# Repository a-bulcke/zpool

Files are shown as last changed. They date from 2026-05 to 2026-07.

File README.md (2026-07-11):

# zpool V2
Carte Zigbbe de gestion de piscine avec mesure pH, Orp, température et pression

### ATTENTION ERREUR R26=0 ohm

zPool

**Les nouveautés :** 

    Filtre sur l'alimentation USB du Xiao

    Régulation LDO coté capteurs pour enlever les bruits provenant du Xiao et de l'ADM3260.

    Alimentation AOP et ADS1115 en 4.7V

    Utilisation d'une référence de tension 2.35V (4.7/2) au lieu des ponts diviseurs non bufferisés

    Gain Orp passe de 2.32 à 2

    Guard ring pour éviter les courants de fuite au niveau des sondes (dont l'impédance est très élevé ce qui peut expliquer l'éventuelle dérive sur la v1.0)

    Connecteur I2C en 3.3V pour écran Oled ou autre

**Sources :** 

https://github.com/Loic74650/pH_Orp_Board

https://www.360customs.de/fr/2019/12/orp-redox-ph-elektrometer-shield-fuer-wemos-d1-mini-mit-lmp7721-ads1115-adm3260/

https://www.ti.com/lit/ds/symlink/lmp7721.pdf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

## Xiao ESP32C6
Utilisation d'un ESP32C6 pour en faire un routeur Zigbee.

Fonctionne avec Zigbee2Mqtt sous Home Assistant.

La carte mesure le pH, l’ Orp, la température et la pression.

La gestion des pompes est assurée par des prises Zigbee c’est plus simple que d’ajouter des relais à la carte.

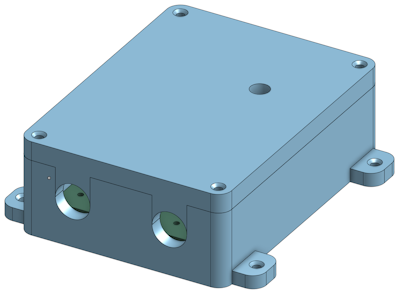
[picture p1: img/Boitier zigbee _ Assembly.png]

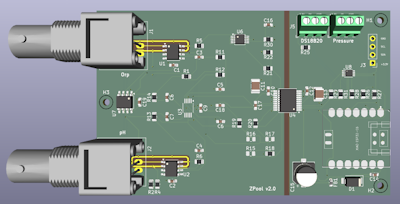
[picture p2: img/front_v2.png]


Capteur de température DS18B20


Capteur de pression 30 Psi


# Branchements #
## température et pression ##



## pH et Orp ##

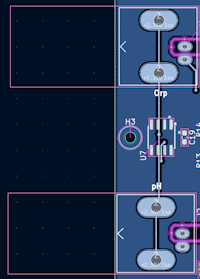
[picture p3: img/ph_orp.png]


# Zigbee2Mqtt #
Dans Zigbee2mqtt sous Home Assistant, laller dans le menu `Paramètres` puis `console de developpement - convertisseurs externes` :



Créer un nouveau convertisseur (de nom ZPool.js) et coller le contenu de [ZPool.js](https://github.com/a-bulcke/zpool/blob/main/zigbee2mqtt/ZPool.js)

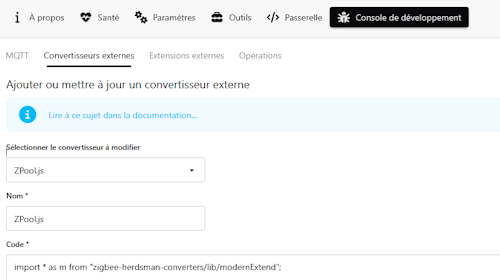
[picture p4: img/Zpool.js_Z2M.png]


Redémarrer Zigbee2mqtt puis autoriser l'association.

# Mise à jour

## Programmation - Mise à jour

Dans Arduino IDE

Dans File - Preferences... ajouter :

```https://espressif.github.io/arduino-esp32/package_esp32_index.json```

Choisir une carte XIAO_ESP32C6 :

<img width="678" height="305" alt="image" src="https://github.com/user-attachments/assets/d0d6836c-16a6-46c1-87e2-4705d107b142" />

<img width="360" height="305" alt="image" src="https://github.com/user-attachments/assets/5ee56a3f-e4a6-4aa4-a9af-70fcf8b1b8bd" />

Dans Tools choisir Partition scheme: "Zigbee ZCZR 4MB with spiffs" et Zigbee Mode: "ZCZR (coordinator/router)"

<img width="718" height="263" alt="image" src="https://github.com/user-attachments/assets/d69159c5-b0cd-445a-aaad-a5ce7c5304e6" />

Et copier coller le code dans Arduino IDE :

Mettre ```Erase All Flash before sketch Upload : Disabled``` pour conserver l'appairage zigbee

<img width="504" height="548" alt="image" src="https://github.com/user-attachments/assets/88b685ce-3d30-4234-acdd-36c6a44c3e30" />

Installer les bibliothèques : 
Chercher et installer : 
```
#include "OneWireESP32.h" //esp32-ds18b20 par junkfix
#include <ADS1X15.h> //ADS1X15 par Rob Tillaart
#include "RunningAverage.h" // RunningAverage par Rob Tillaart
```
<img width="340" height="249" alt="image" src="https://github.com/user-attachments/assets/61d23882-cdc2-45de-8c77-091b2764080c" />

<img width="333" height="298" alt="image" src="https://github.com/user-attachments/assets/ee26f123-cd82-4b68-ad05-28b897d303d5" />

Puis Upload :

<img width="432" height="128" alt="image" src="https://github.com/user-attachments/assets/c4538ff6-32a3-41d7-afa3-70f6845f523d" />

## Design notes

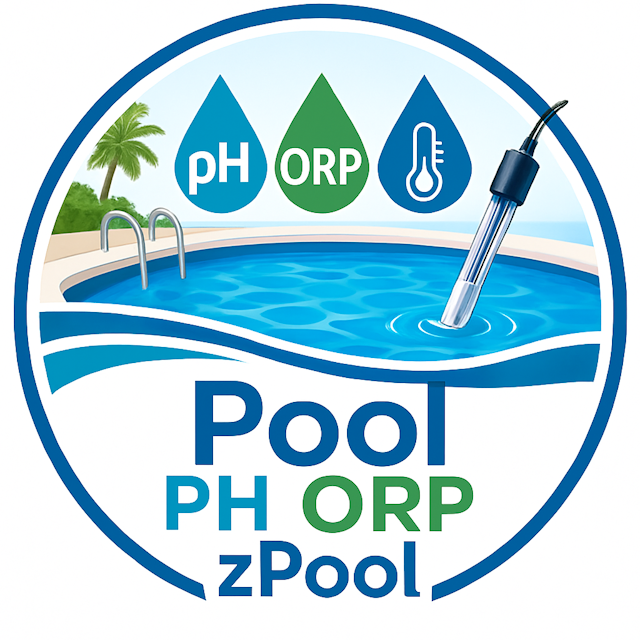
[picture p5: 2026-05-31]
img/zPool_640.png

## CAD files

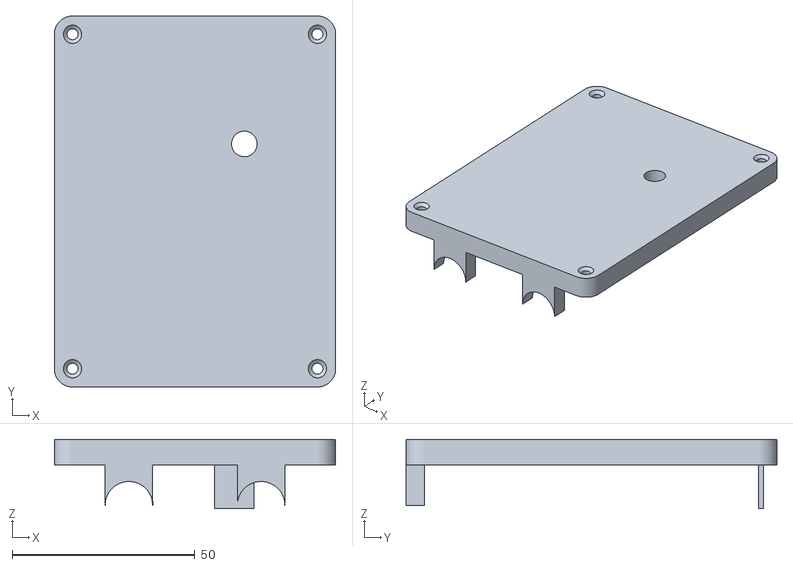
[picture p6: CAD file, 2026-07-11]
stl/couvercle_zigbee_v2.stl
77.0 x 101.5 x 18.9

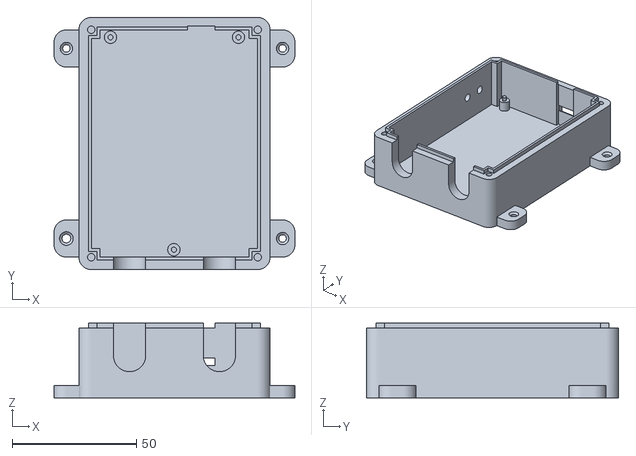
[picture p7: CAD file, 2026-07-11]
stl/boitier_zigbee_v2.stl
97.0 x 101.5 x 30.0

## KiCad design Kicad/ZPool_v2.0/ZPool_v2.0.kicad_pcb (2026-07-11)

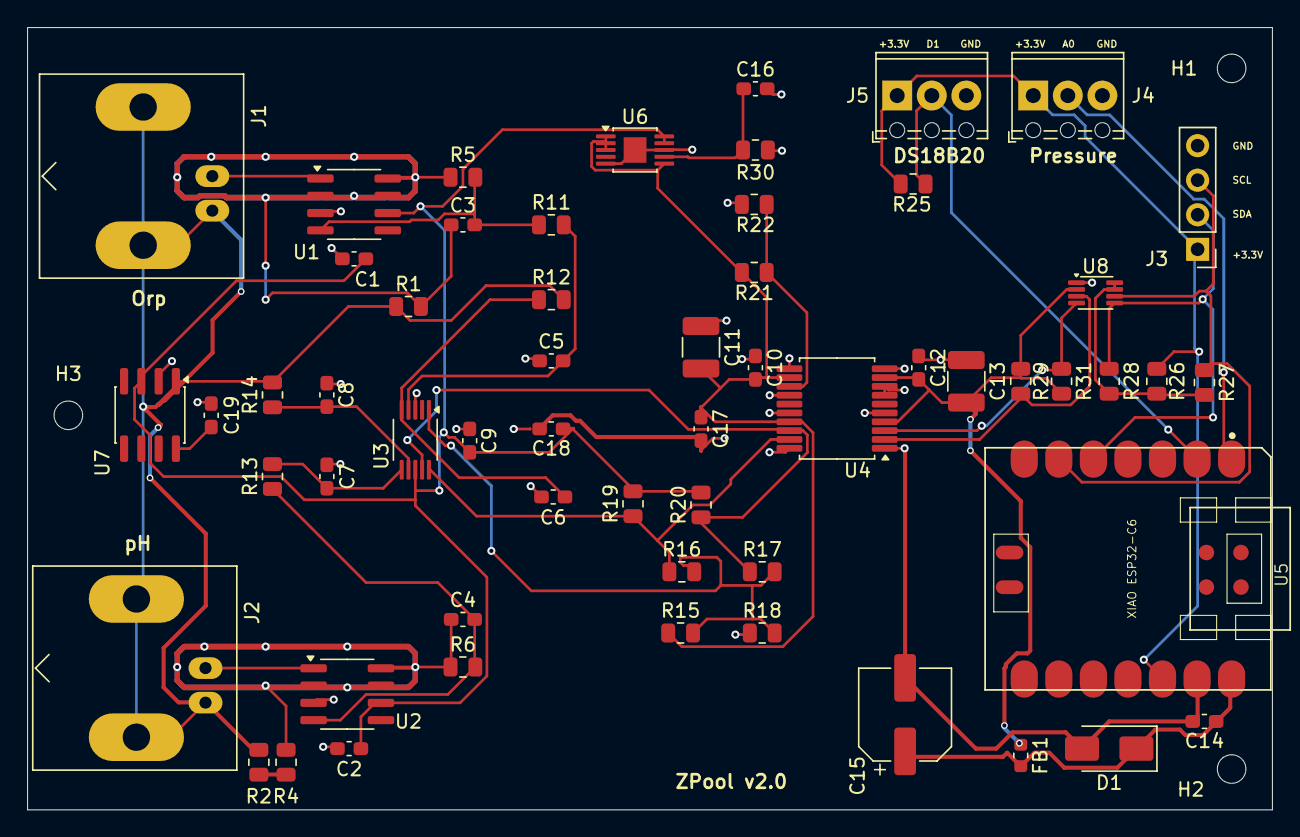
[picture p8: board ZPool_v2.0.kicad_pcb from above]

Board: 2 copper layers, 91.5 x 57.5 mm, 61 parts (0 on the bottom side), 30 nets.

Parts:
C1, C2, C3, C4, C9, C10, C12: 100nF; C_0603_1608Metric_Pad1.08x0.95mm_HandSolder
C5, C6, C7, C8: 1uF; C_0603_1608Metric_Pad1.08x0.95mm_HandSolder
C11, C13: 10uF; C_1210_3225Metric_Pad1.33x2.70mm_HandSolder
C14: 100n; C_0603_1608Metric_Pad1.08x0.95mm_HandSolder
C15: 470u; CP_Elec_6.3x5.7
C16: 10nF; C_0603_1608Metric_Pad1.08x0.95mm_HandSolder
C17, C18: 4.7uF; C_0603_1608Metric_Pad1.08x0.95mm_HandSolder
C19: 1nF; C_0603_1608Metric_Pad1.08x0.95mm_HandSolder
D1: SMAJ5.0A; D_SMA
FB1: FerriteBead; L_0603_1608Metric
H1, H2, H3: MountingHole; MountingHole_2.1mm
J1, J2: Conn_Coaxial; BNC_Amphenol_B6252HB-NPP3G-50_Horizontal
J3: Conn_01x04_Male; PinHeader_1x04_P2.54mm_Vertical
J4: Conn_Pression; TerminalBlock_Phoenix_MPT-0,5-3-2.54_1x03_P2.54mm_Horizontal
J5: Conn_DS18B20; TerminalBlock_Phoenix_MPT-0,5-3-2.54_1x03_P2.54mm_Horizontal
R1, R5: 150K; R_0805_2012Metric
R2: 100K; R_0805_2012Metric
R4: 51K; R_0805_2012Metric
R6: 1M; R_0805_2012Metric
R11, R12, R13, R14: 10K; R_0805_2012Metric
R15, R16, R17, R18: 0; R_0805_2012Metric
R19, R20, R25, R27, R28, R29, R31: 4K7; R_0805_2012Metric
R21: R30.9K; R_0805_2012Metric
R22: R10K; R_0805_2012Metric
R26: 200K; R_0805_2012Metric
R30: 47K; R_0805_2012Metric
U1, U2: LMP7721MA/NOPB; SOIC-8_3.9x4.9mm_P1.27mm
U3: ADS1115IDGS; VSSOP-10_3x3mm_P0.5mm
U4: ADM3260; SSOP-20_5.3x7.2mm_P0.65mm
U5: XIAO ESP32-C6; Seeeduino XIAO-MOUDLE14P-2.54-21X17.8MM
U6: LT3042xMSE; MSOP-10-1EP_3x3mm_P0.5mm_EP1.68x1.88mm
U7: TLE2426xD; SOIC-8_3.9x4.9mm_P1.27mm
U8: PCA9306; VSSOP-8_2.3x2mm_P0.5mm

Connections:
+2.35V Iso: J1.2 (Ext), J2.2 (Ext), R1.1, R2.1, R12.2, R14.2, U7.1 (OUT)
+3.3V: J3.1, J4.1, J5.1, R25.1, R26.2, U5.12 (3V3)
+4.7V Iso: C1.2, C2.2, C9.2, C18.1, R19.2, R20.2, U1.6, U2.6, U3.8 (VDD), U6.9 (OUTS), U6.10 (OUT), U7.3 (IN)
+5V: C12.2, C13.2, FB1.1, R29.2, R31.2, U4.4 (VDDP), U4.9 (VIN), U8.2 (VREF1)
+5V Iso: C10.2, C11.2, C17.1, R15.1, R21.1, U4.12 (VISO), U4.17 (VDDISO), U6.1 (IN), U6.2 (IN), U6.3 (EN/UV), U6.6 (PGFB)
+5V_XIAO: C14.1, C15.1, D1.1 (A1), FB1.2, U5.14 (5V)
A0: J4.2, U5.1 (PA02_A0_D0)
D1: J5.2, R25.2, U5.2 (PA4_A1_D1)
GND: C12.1, C13.1, C14.2, C15.2, D1.2 (A2), J3.4, J4.3, J5.3, U4.1 (GNDP@1), U4.5 (GNDP@2), U4.7 (GNDP@2), U4.8 (PDIS), U4.10 (GNDP@2), U5.13 (GND), U8.1 (GND)
GND Iso: C1.1, C2.1, C5.1, C6.1, C7.1, C8.1, C9.1, C10.1, C11.1, C16.2, C17.2, C18.2, C19.2, R18.1, R22.1, R30.1, U1.3, U2.3, U3.3 (GND), U4.11 (GNDISO@2), U4.14 (GNDISO@2), U4.16 (GNDISO@2), U4.20 (GNDISO@1), U6.5 (ILIM), U6.8 (GND), U6.11 (GND), U7.2 (COMMON)
unnamed: C3.2, R5.2, R11.1, U1.4
unnamed: C4.2, R6.2, R13.1, U2.4
unnamed: J1.1 (In), U1.1
unnamed: J2.1 (In), U2.1
unnamed: R2.2, R4.1
unnamed: R15.2, R16.2, R17.2, R18.2, U3.1 (ADDR)
unnamed: C5.2, R11.2, U3.4 (AIN0)
unnamed: C6.2, R12.1, U3.5 (AIN1)
unnamed: C7.2, R13.2, U3.6 (AIN2)
unnamed: C8.2, R14.1, U3.7 (AIN3)
unnamed: R16.1, R19.1, U3.10 (SCL), U4.19 (SCL1)
unnamed: R17.1, R20.1, U3.9 (SDA), U4.18 (SDA1)
unnamed: R21.2, R22.2, U4.13 (VSEL)
unnamed: C16.1, R30.2, U6.7 (SET)
unnamed: C19.1, U7.8 (NOISE_REDUCTION)
unnamed: R26.1, R27.2, R28.2, U8.7 (VREF2), U8.8 (EN)
SCL: R29.1, U4.2 (SCL2), U8.3 (SCL1)
SCL3.3: J3.3, R27.1, U5.6 (PA9_A5_D5_SCL), U8.6 (SCL2)
SDA: R31.1, U4.3 (SDA2), U8.4 (SDA1)
SDA3.3: J3.2, R28.1, U5.5 (PA8_A4_D4_SDA), U8.5 (SDA2)

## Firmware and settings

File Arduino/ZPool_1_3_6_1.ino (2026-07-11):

/**
 * @brief Publication zigbee de la temperature (DS18B20), pression (AN), pH et ORP (mV) avec calibration
 * @version 1.3.6.1
 * @changelog
 *   1.3.6.1 - Correctif remontees pH/ORP : le report periodique "max interval" de la stack
 *             ESP Zigbee ne se declenche pas si l'attribut n'est jamais touche via
 *             setAnalogInput(). Heartbeat firmware ajoute : remontee forcee toutes les
 *             report_time secondes (60 s) meme sans franchissement de seuil.
 *   1.3.6   - Optimisations :
 *             * Une seule lecture DS18B20 par cycle (T passee en parametre a readPH)
 *             * Conversion DS18B20 non bloquante : lectures ADS1115/pression pendant les 750 ms
 *             * Suppression du setAnalogInput inconditionnel (le seuillage SEUIL_PH/SEUIL_ORP est
 *               desormais reellement effectif)
 *             * Calibration testee EN TETE de boucle : plus de cycle de mesure/remontee parasite
 *               avec la sonde dans la solution tampon (suppression de calibInProgress)
 *             * Debounce NVS sur les sliders Z2M (commit differe 5 s, usure flash reduite)
 *             * readTemp robuste : code erreur verifie, rejet 85.0/hors plage, derniere valeur valide
 *             * Version centralisee (FW_VERSION_*), timeout connexion Zigbee (reboot),
 *               vTaskDelayUntil pour periode de cycle constante, fix uint32_t millis()
 *   1.3.5.2 - Seuils de remontee pH et Orp dans sensors_values_update et pas dans setAnalogInputReporting
 *   1.3.5.1 - inversion broches ADS1115 pour ph et ORP
 *   1.3.5   - Pas de remontee pendant la calibration - timing lecture temperature a 750ms
 *   1.3.3   - Correction thermique par equation de Nernst
 *             mv normalise a T_cal avant application du polynome. Point isopotentiel = pH 7.
 *             S(T) = -0.1984 * (273.15 + T)  [mV/pH]
 *   1.3.2   - Correction stack overflow
 *   1.3.1   - Valeurs des solutions de calibration ajustables depuis Z2M/HA (analog output EP13-16)
 *   1.3.0   - Ajout calibration pH 10.01 (ep7), equation polynomiale degre 2, filtre de Kalman pH+ORP
 *   1.2.4   - OTA
 */

#ifndef ZIGBEE_MODE_ZCZR
#error "Zigbee coordinator/router device mode is not selected in Tools->Zigbee mode"
#endif

#include "Zigbee.h"
#include "OneWireESP32.h"   // esp32-ds18b20 par junkfix
#include <ADS1X15.h>        // ADS1X15 par Rob Tillaart
#include <Preferences.h>
#include "RunningAverage.h" // RunningAverage par Rob Tillaart

/* ──────────────────────────────────────────────────────────────
 *  Version firmware (source unique)
 * ────────────────────────────────────────────────────────────── */
#define FW_VERSION_STR   "1.3.6.1"
#define FW_VERSION_ZB    136          // setVersion / setHardwareVersion (uint8)
#define FW_VERSION_OTA   0x01030601   // fileVersion OTA (maj.min.patch.build)

/* ──────────────────────────────────────────────────────────────
 *  Endpoints Zigbee
 * ────────────────────────────────────────────────────────────── */
// Mesures
#define TEMP_SENSOR_ENDPOINT_NUMBER       10
#define PRESSURE_SENSOR_ENDPOINT_NUMBER   11
#define ANALOG_DEVICE_PH_ENDPOINT_NUMBER   9
#define ANALOG_DEVICE_ORP_ENDPOINT_NUMBER 12

// Déclencheurs de calibration (binary output → écriture Z2M)
#define ZIGBEE_PH401_ENDPOINT   4
#define ZIGBEE_PH700_ENDPOINT   5
#define ZIGBEE_ORP256_ENDPOINT  6
#define ZIGBEE_PH1001_ENDPOINT  7

// Valeurs des solutions (analog output → slider Z2M/HA)
#define ZIGBEE_PH401_VAL_EP    13   // Valeur cible pH point 1  (ex : 4.01 ou 6.86)
#define ZIGBEE_PH700_VAL_EP    14   // Valeur cible pH point 2  (ex : 7.00 ou 6.86)
#define ZIGBEE_PH1001_VAL_EP   15   // Valeur cible pH point 3  (ex : 10.01 ou 9.18)
#define ZIGBEE_ORP256_VAL_EP   16   // Valeur cible ORP          (ex : 256 ou 240 mV)

// Constantes de mesure et remontée zigbee
#define ORP_GAIN            2.0f
#define SEUIL_PH            0.05f
#define SEUIL_ORP           10.0f
#define report_time         60       // heartbeat de remontée pH/ORP en secondes
#define CYCLE_MS            10000    // période de la tâche capteurs
#define DS18B20_CONV_MS     750      // conversion 12 bits DS18B20
#define NVS_COMMIT_DELAY_MS 5000     // debounce écriture NVS des sliders
#define ZB_CONNECT_TIMEOUT  120000UL // timeout connexion réseau au boot (ms)

/* ──────────────────────────────────────────────────────────────
 *  Filtre de Kalman 1D
 * ────────────────────────────────────────────────────────────── */
struct KalmanFilter1D {
    float x;
    float P;
    float Q;
    float R;
    bool  init;

    KalmanFilter1D(float q = 0.001f, float r = 0.1f)
        : x(0), P(1.0f), Q(q), R(r), init(false) {}

    float update(float z) {
        if (!init) { x = z; P = 1.0f; init = true; return x; }
        P      += Q;
        float K = P / (P + R);
        x      += K * (z - x);
        P      *= (1.0f - K);
        return x;
    }

    void reset() { init = false; }
};

/* ──────────────────────────────────────────────────────────────
 *  Prototypes
 * ────────────────────────────────────────────────────────────── */
void     printCalibSummary();
float    getTempChecked();
float    readTemp();
uint16_t readPressure();
float    readPHmV();
float    readORPmV();
float    computePH(float mv, float T);
float    computeORP(float mv_raw);
void     setPH4(bool);
void     setPH7(bool);
void     setPH10(bool);
void     setORP(bool);
void     onPH4ValChange(float);
void     onPH7ValChange(float);
void     onPH10ValChange(float);
void     onORPValChange(float);
void     calibration();
float    mVtopH(float mv, float T = 20.0f);   // défaut ici, PAS dans la définition
bool     computePolyCoeffs();
void     commitPendingNVS();
static void sensors_values_update(void *);
void     otaStateChange(bool);

/* ──────────────────────────────────────────────────────────────
 *  Matériel
 * ────────────────────────────────────────────────────────────── */
uint8_t analogPression = A0;
uint8_t button    = BOOT_PIN;
OneWire32 ds(1);
ADS1115 ADS(0x48);
Preferences calib;

/* ──────────────────────────────────────────────────────────────
 *  Structures de calibration
 * ────────────────────────────────────────────────────────────── */
struct sonde {
    float ph;       // Valeur pH (ou mV ORP) de la solution — réglable depuis Z2M
    float mv;       // Tension mesurée lors de la calibration
    float t;        // Température lors de la calibration
    bool  cal = false;
};

struct sonde ph401;    // Point 1 : pH ~4
struct sonde ph700;    // Point 2 : pH ~7
struct sonde ph1001;   // Point 3 : pH ~10
struct sonde orp256;   // ORP

/* ──────────────────────────────────────────────────────────────
 *  Écritures NVS différées (debounce sliders Z2M)
 *  La valeur est appliquée en RAM immédiatement (callback),
 *  le commit flash n'a lieu qu'après NVS_COMMIT_DELAY_MS de stabilité.
 * ────────────────────────────────────────────────────────────── */
struct PendingNVS {
    const char* key;
    float       value;
    bool        dirty;
    uint32_t    lastChange;
};

PendingNVS pendPH4  = { "ph401",  0.0f, false, 0 };
PendingNVS pendPH7  = { "ph700",  0.0f, false, 0 };
PendingNVS pendPH10 = { "ph1001", 0.0f, false, 0 };
PendingNVS pendORP  = { "orp",    0.0f, false, 0 };

void markPending(PendingNVS &p, float val) {
    p.value      = val;
    p.dirty      = true;
    p.lastChange = millis();
}

void commitPendingNVS() {
    PendingNVS* all[4] = { &pendPH4, &pendPH7, &pendPH10, &pendORP };
    for (PendingNVS* p : all) {
        if (p->dirty && (millis() - p->lastChange) > NVS_COMMIT_DELAY_MS) {
            calib.putFloat(p->key, p->value);
            p->dirty = false;
            Serial.printf("NVS commit : %s = %.2f\r\n", p->key, p->value);
        }
    }
}

/* Coefficients polynôme : pH = poly_a·mV² + poly_b·mV + poly_c */
float poly_a = 0.0f, poly_b = 0.0f, poly_c = 0.0f;
bool  poly_valid = false;

// Constante de Nernst : S(T) = NERNST_K * (273.15 + T°C)  →  mV/pH
// À 25°C : S = -0.1984 * 298.15 = -59.16 mV/pH
static constexpr float NERNST_K = -0.1984f;

float pression_max;

/* Filtres de Kalman */
KalmanFilter1D kfPH (0.001f, 0.05f);
KalmanFilter1D kfORP(0.1f,   3.0f);

uint64_t addr[2];
RunningAverage mVmoyen(100);

/* ──────────────────────────────────────────────────────────────
 *  Endpoints Zigbee
 * ────────────────────────────────────────────────────────────── */
// Mesures
ZigbeeAnalog         zbAnalogPH       = ZigbeeAnalog(ANALOG_DEVICE_PH_ENDPOINT_NUMBER);
ZigbeeTempSensor     zbTempSensor     = ZigbeeTempSensor(TEMP_SENSOR_ENDPOINT_NUMBER);
ZigbeePressureSensor zbPressureSensor = ZigbeePressureSensor(PRESSURE_SENSOR_ENDPOINT_NUMBER);
ZigbeeAnalog         zbAnalogORP      = ZigbeeAnalog(ANALOG_DEVICE_ORP_ENDPOINT_NUMBER);

// Déclencheurs calibration
ZigbeeBinary zbBinaryPH4  = ZigbeeBinary(ZIGBEE_PH401_ENDPOINT);
ZigbeeBinary zbBinaryPH7  = ZigbeeBinary(ZIGBEE_PH700_ENDPOINT);
ZigbeeBinary zbBinaryPH10 = ZigbeeBinary(ZIGBEE_PH1001_ENDPOINT);
ZigbeeBinary zbBinaryORP  = ZigbeeBinary(ZIGBEE_ORP256_ENDPOINT);

// Valeurs des solutions (analog output — slider Z2M/HA)
ZigbeeAnalog zbValPH4   = ZigbeeAnalog(ZIGBEE_PH401_VAL_EP);
ZigbeeAnalog zbValPH7   = ZigbeeAnalog(ZIGBEE_PH700_VAL_EP);
ZigbeeAnalog zbValPH10  = ZigbeeAnalog(ZIGBEE_PH1001_VAL_EP);
ZigbeeAnalog zbValORP   = ZigbeeAnalog(ZIGBEE_ORP256_VAL_EP);

volatile bool otaInProgress = false;
volatile bool initialized   = false;

/* ══════════════════════════════════════════════════════════════
 *  DIAGNOSTIC — Affichage des paramètres NVS au démarrage
 * ══════════════════════════════════════════════════════════════ */
void printCalibSummary() {
    const char* SEP  = "==================================================";
    const char* SEP2 = "--------------------------------------------------";

    Serial.println();
    Serial.println(SEP);
    Serial.printf ("       ZPool v%s — PARAMETRES DE CALIBRATION (NVS)\r\n", FW_VERSION_STR);
    Serial.println(SEP);

    // ── pH : solutions ───────────────────────────────────────────
    Serial.println("  [Solutions pH]");
    Serial.printf ("    Point 1  : sol=%6.3f pH  mv=%+9.2f mV  T=%5.1f deg C\r\n",
                   ph401.ph,  ph401.mv,  ph401.t);
    Serial.printf ("    Point 2  : sol=%6.3f pH  mv=%+9.2f mV  T=%5.1f deg C\r\n",
                   ph700.ph,  ph700.mv,  ph700.t);
    Serial.printf ("    Point 3  : sol=%6.3f pH  mv=%+9.2f mV  T=%5.1f deg C\r\n",
                   ph1001.ph, ph1001.mv, ph1001.t);

    // ── pH : pente de Nernst aux 3 températures de calibration ───
    Serial.println(SEP2);
    Serial.println("  [Pentes de Nernst]");
    Serial.printf ("    S(T_cal1=%5.1f deg C) = %+7.3f mV/pH\r\n",
                   ph401.t,  NERNST_K * (273.15f + ph401.t));
    Serial.printf ("    S(T_cal2=%5.1f deg C) = %+7.3f mV/pH  <- pivot isopotentiel\r\n",
                   ph700.t,  NERNST_K * (273.15f + ph700.t));
    Serial.printf ("    S(T_cal3=%5.1f deg C) = %+7.3f mV/pH\r\n",
                   ph1001.t, NERNST_K * (273.15f + ph1001.t));

    // ── pH : polynôme ────────────────────────────────────────────
    Serial.println(SEP2);
    Serial.println("  [Polynome  pH = a*mV^2 + b*mV + c]");
    if (poly_valid) {
        Serial.printf("    a = %+.8f\r\n", poly_a);
        Serial.printf("    b = %+.6f  mV/pH\r\n", poly_b);
        Serial.printf("    c = %+.4f  pH\r\n",    poly_c);
        float r1 = poly_a*ph401.mv *ph401.mv  + poly_b*ph401.mv  + poly_c - ph401.ph;
        float r2 = poly_a*ph700.mv *ph700.mv  + poly_b*ph700.mv  + poly_c - ph700.ph;
        float r3 = poly_a*ph1001.mv*ph1001.mv + poly_b*ph1001.mv + poly_c - ph1001.ph;
        Serial.printf("    Residus : r1=%+.4f  r2=%+.4f  r3=%+.4f pH\r\n", r1, r2, r3);
        Serial.println("    Statut  : OK (3 points)");
    } else {
        Serial.println("    Statut  : FALLBACK LINEAIRE (< 3 points ou systeme singulier)");
        float a_lin = (ph700.ph - ph401.ph) / (ph700.mv - ph401.mv);
        float b_lin =  ph700.ph - a_lin * ph700.mv;
        Serial.printf("    a_lin = %+.6f mV/pH   b_lin = %+.4f pH\r\n", a_lin, b_lin);
    }

    // ── ORP ──────────────────────────────────────────────────────
    Serial.println(SEP2);
    Serial.println("  [ORP]");
    Serial.printf ("    Solution  : %7.1f mV  (cible)\r\n",  orp256.ph);
    Serial.printf ("    Mesure    : %7.2f mV  (lors de la calibration)\r\n", orp256.mv);
    Serial.printf ("    Offset    : %+7.2f mV\r\n", orp256.ph - orp256.mv);

    // ── Pression ─────────────────────────────────────────────────
    Serial.println(SEP2);
    Serial.println("  [Pression]");
    Serial.printf ("    Pleine echelle : %.0f hPa  (%.2f bar)\r\n",
                   pression_max, pression_max / 1000.0f);

    // ── Kalman ───────────────────────────────────────────────────
    Serial.println(SEP2);
    Serial.println("  [Filtres Kalman]");
    Serial.printf ("    pH   Q=%.4f  R=%.4f\r\n", kfPH.Q,  kfPH.R);
    Serial.printf ("    ORP  Q=%.4f  R=%.4f\r\n", kfORP.Q, kfORP.R);

    // ── Mémoire heap FreeRTOS ────────────────────────────────────
    Serial.println(SEP2);
    Serial.println("  [Systeme]");
    Serial.printf ("    Heap libre    : %lu octets\r\n", (unsigned long)esp_get_free_heap_size());
    Serial.printf ("    Heap min ever : %lu octets\r\n", (unsigned long)esp_get_minimum_free_heap_size());
    Serial.println(SEP);
    Serial.println();
}
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
void loop() {
    if (digitalRead(button) == LOW) {
        delay(100);
        uint32_t startTime = millis();   // uint32_t : robuste au wrap de millis()
        while (digitalRead(button) == LOW) {
            delay(50);
            if ((millis() - startTime) > 3000) {
                Serial.println("Factory reset Zigbee et reboot dans 1s.");
                delay(1000);
                Zigbee.factoryReset();
            }
        }
    }
    delay(100);
}

/* ══════════════════════════════════════════════════════════════
 *  CALLBACKS — VALEURS DES SOLUTIONS (analog output)
 *  RAM immédiate + commit NVS différé (debounce, voir commitPendingNVS)
 * ══════════════════════════════════════════════════════════════ */

/**
 * @brief Appelé par Z2M/HA quand l'utilisateur modifie la valeur cible pH4.
 *        Mise à jour RAM + recalcul du polynôme. Commit NVS différé (5 s).
 */
void onPH4ValChange(float val) {
    if (!initialized) return;   // ignore appels spurieux au démarrage
    // Garde-fou plage physique cohérente
    if (val < 3.0f || val > 6.5f) {
        Serial.printf("WARN: Valeur pH4 hors plage [3.0-6.5] : %.2f ignoree\r\n", val);
        return;
    }
    if (fabsf(val - ph401.ph) < 0.005f) return;   // pas de changement significatif
    ph401.ph = val;
    markPending(pendPH4, val);
    Serial.printf("Solution pH4 mise a jour : %.2f (NVS differe)\r\n", val);
    computePolyCoeffs();
    kfPH.reset();
}

void onPH7ValChange(float val) {
    if (!initialized) return;
    if (val < 5.5f || val > 8.5f) {
        Serial.printf("WARN: Valeur pH7 hors plage [5.5-8.5] : %.2f ignoree\r\n", val);
        return;
    }
    if (fabsf(val - ph700.ph) < 0.005f) return;
    ph700.ph = val;
    markPending(pendPH7, val);
    Serial.printf("Solution pH7 mise a jour : %.2f (NVS differe)\r\n", val);
    computePolyCoeffs();
    kfPH.reset();
}

void onPH10ValChange(float val) {
    if (!initialized) return;
    if (val < 8.5f || val > 11.5f) {
        Serial.printf("WARN: Valeur pH10 hors plage [8.5-11.5] : %.2f ignoree\r\n", val);
        return;
    }
    if (fabsf(val - ph1001.ph) < 0.005f) return;
    ph1001.ph = val;
    markPending(pendPH10, val);
    Serial.printf("Solution pH10 mise a jour : %.2f (NVS differe)\r\n", val);
    computePolyCoeffs();
    kfPH.reset();
}

void onORPValChange(float val) {
    if (!initialized) return;
    if (val < 50.0f || val > 700.0f) {
        Serial.printf("WARN: Valeur ORP hors plage [50-700] mV : %.1f ignoree\r\n", val);
        return;
    }
    if (fabsf(val - orp256.ph) < 0.5f) return;
    orp256.ph = val;
    markPending(pendORP, val);
    Serial.printf("Solution ORP mise a jour : %.1f mV (NVS differe)\r\n", val);
    kfORP.reset();
}

/* ══════════════════════════════════════════════════════════════
 *  CALLBACKS — DÉCLENCHEURS DE CALIBRATION (binary output)
 * ══════════════════════════════════════════════════════════════ */
void setPH4(bool value)  { Serial.printf("Calib pH4(%d)  : %f\r\n", value, ph401.ph);  ph401.cal  = value; }
void setPH7(bool value)  { Serial.printf("Calib pH7(%d)  : %f\r\n", value, ph700.ph);  ph700.cal  = value; }
void setPH10(bool value) { Serial.printf("Calib pH10(%d) : %f\r\n", value, ph1001.ph); ph1001.cal = value; }
void setORP(bool value)  { Serial.printf("Calib ORP(%d)  : %f\r\n", value, orp256.ph); orp256.cal = value; }

/* ══════════════════════════════════════════════════════════════
 *  LECTURES CAPTEURS
 * ══════════════════════════════════════════════════════════════ */

/**
 * @brief Récupère la température APRÈS conversion (ds.request() déjà fait).
 *        Vérifie le code d'erreur et la plausibilité ; en cas d'échec,
 *        retourne la dernière valeur valide (85.0 = power-on reset DS18B20).
 */
float getTempChecked() {
    static float lastGood = 20.0f;
    float t = NAN;
    uint8_t err = ds.getTemp(addr[0], t);
    if (err || isnan(t) || t == 85.0f || t < -20.0f || t > 60.0f) {
        Serial.printf("WARN readTemp err=%u val=%.2f -> garde %.2f degC\r\n", err, t, lastGood);
        return lastGood;
    }
    lastGood = t;
    Serial.printf("Temp : %.2f deg C\r\n", t);
    return t;
}

/**
 * @brief Lecture bloquante (request + 750 ms + getTemp).
 *        Utilisée uniquement par la calibration ; la tâche capteurs
 *        utilise le schéma non bloquant (request / lectures / getTemp).
 */
float readTemp() {
    ds.request();
    vTaskDelay(pdMS_TO_TICKS(DS18B20_CONV_MS));
    return getTempChecked();
}

uint16_t readPressure() {
    uint32_t mv  = analogReadMilliVolts(A0);
    uint16_t hPa = (uint16_t)((float)mv / 3300.0f * pression_max);
    Serial.printf("Pression : %d hPa\r\n", hPa);
    return hPa;
}

float readPHmV() {
    int16_t v = ADS.readADC_Differential_2_3();
    return ADS.toVoltage(v) * 1000.0f;
}

float readORPmV() {
    int16_t v = ADS.readADC_Differential_0_1();
    return ADS.toVoltage(v) * 1000.0f / ORP_GAIN;
}

/**
 * @brief Conversion mV → pH filtré. La température est fournie par
 *        l'appelant : une seule lecture DS18B20 par cycle.
 */
float computePH(float mv, float T) {
    float S_T     = NERNST_K * (273.15f + T);
    float ph_raw  = mVtopH(mv, T);
    float ph_filt = kfPH.update(ph_raw);
    Serial.printf("pH  mv=%.2f  T=%.1f degC  S(T)=%.3f mV/pH  brut=%.3f  Kalman=%.3f\r\n",
                  mv, T, S_T, ph_raw, ph_filt);
    return ph_filt;
}

float computeORP(float mv_raw) {
    float mv256    = mv_raw + (orp256.ph - orp256.mv);
    float orp_filt = kfORP.update(mv256);
    Serial.printf("ORP brut=%.1f mV  Kalman=%.1f mV\r\n", mv256, orp_filt);
    return orp_filt;
}

/* ══════════════════════════════════════════════════════════════
 *  CALCUL DU POLYNÔME (3 points)
 * ══════════════════════════════════════════════════════════════ */
bool computePolyCoeffs() {
    float mv[3]  = { ph401.mv,  ph700.mv,  ph1001.mv  };
    float pH_[3] = { ph401.ph,  ph700.ph,  ph1001.ph  };

    float M[3][4];
    for (int i = 0; i < 3; i++) {
        M[i][0] = mv[i] * mv[i];
        M[i][1] = mv[i];
        M[i][2] = 1.0f;
        M[i][3] = pH_[i];
    }

    for (int col = 0; col < 3; col++) {
        int   maxRow = col;
        float maxVal = fabsf(M[col][col]);
        for (int row = col + 1; row < 3; row++) {
            if (fabsf(M[row][col]) > maxVal) { maxVal = fabsf(M[row][col]); maxRow = row; }
        }
        if (maxVal < 1e-8f) { poly_valid = false; return false; }
        if (maxRow != col) {
            for (int j = 0; j < 4; j++) { float t = M[col][j]; M[col][j] = M[maxRow][j]; M[maxRow][j] = t; }
        }
        float pivot = M[col][col];
        for (int j = col; j < 4; j++) M[col][j] /= pivot;
        for (int row = 0; row < 3; row++) {
            if (row == col) continue;
            float f = M[row][col];
            for (int j = col; j < 4; j++) M[row][j] -= f * M[col][j];
        }
    }

    poly_a = M[0][3]; poly_b = M[1][3]; poly_c = M[2][3];

    float e4  = fabsf(poly_a*ph401.mv *ph401.mv  + poly_b*ph401.mv  + poly_c - ph401.ph);
    float e7  = fabsf(poly_a*ph700.mv *ph700.mv  + poly_b*ph700.mv  + poly_c - ph700.ph);
    float e10 = fabsf(poly_a*ph1001.mv*ph1001.mv + poly_b*ph1001.mv + poly_c - ph1001.ph);
    poly_valid = (e4 < 0.01f) && (e7 < 0.01f) && (e10 < 0.01f);

    Serial.printf("Poly : a=%.8f b=%.6f c=%.4f [%s]\r\n",
                  poly_a, poly_b, poly_c, poly_valid ? "OK" : "INVALIDE");
    return poly_valid;
}
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

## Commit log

2026-01-31 Add temperature and pressure sensor images to README
2026-01-31 Enhance README for ESP32C6 Zigbee router
    Updated the description of the ESP32C6 usage and added functionality details. Included images with specified widths.
2026-02-14 Update README with Arduino IDE configuration details
    Added Arduino IDE setup instructions for XIAO_ESP32C6.
2026-02-14 Update README with new connection sections
    Added sections for temperature, pressure, pH, and Zigbee2Mqtt.
2026-03-18 Fix image link format for DS18B20 sensor
    Updated the image link format for temperature sensor.
2026-03-18 Fix image link for DS18B20 temperature sensor
    Updated the image link for the DS18B20 temperature sensor in the README.
2026-03-18 Change temperature sensor image URL
    Updated image link for temperature sensor in README.
2026-03-18 Fix image URLs in README
    Updated image URLs for temperature and pressure sensors.
2026-03-28 Add Zigbee temperature and pressure sensor code
2026-03-29 Update version to 1.11 and add external antenna config
2026-03-29 Add initial configuration for pool sensors
2026-03-29 Configure WIFI_ENABLE pin for external antenna
2026-03-29 Update README with sensor images and links
    Added images and links for temperature and pressure sensors.
2026-03-31 Update README with Arduino IDE programming instructions
    Added instructions for programming with Arduino IDE and configuring Zigbee settings.
2026-05-30 1.3.3 pre release
    Version préliminaire avec choix des solutions d'étalonnage, 3 points d'étalonnage pour le pH, OTA, et filtre de Kalman.
2026-05-30 Upgrade ZPool.js to version 1.3.5
    Updated ZPool.js to version 1.3.5 with new measurements and calibration triggers.
2026-05-30 Bump version to 1.3.5 and update changelog
    Updated version to 1.3.5 with calibration timing adjustments and thermal correction using Nernst equation.
2026-06-02 Change gain setting and update ADC read functions
2026-06-02 Change ADS gain and update ADC readings
2026-06-02 Swap multiplexer channels for ADS1115 sensors
2026-06-02 Update ORP voltage calibration formula
    Adjust calibration calculation for ORP voltage.
2026-06-03 Fix ADS1115 channel assignments in zpool_v1_0.yaml
    Updated ADS1115 channel assignments for pH and ORP sensors.
2026-07-11 Erreur sur R26 (0 ohm)
2026-07-11 0 ohm
2026-07-11 fichiers stl du boitier
    [boitier_zigbee_v2.stl, couvercle_zigbee_v2.stl]
